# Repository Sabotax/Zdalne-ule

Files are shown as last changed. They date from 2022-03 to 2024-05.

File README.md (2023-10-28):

# Zdalne-ule
Projekt przejściowy oraz praca inżynierska oraz projekt kontynuowany prywatnie.
Polega na zbieraniu danych z uli pszczeli w celu ich zdalnego wykorzystania w optymalizacji pracy pszczelarza.  
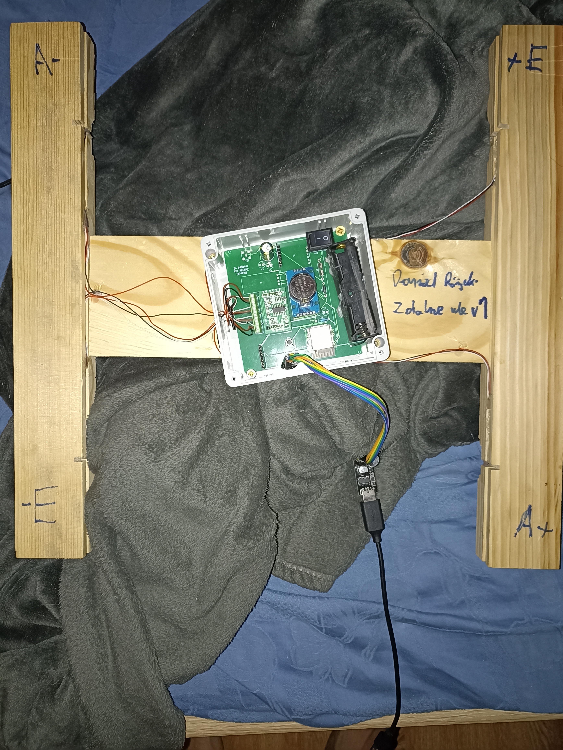
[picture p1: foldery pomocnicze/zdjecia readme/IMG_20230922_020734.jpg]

Używane technologie: 
	- C++ od strony mikontrolerów,
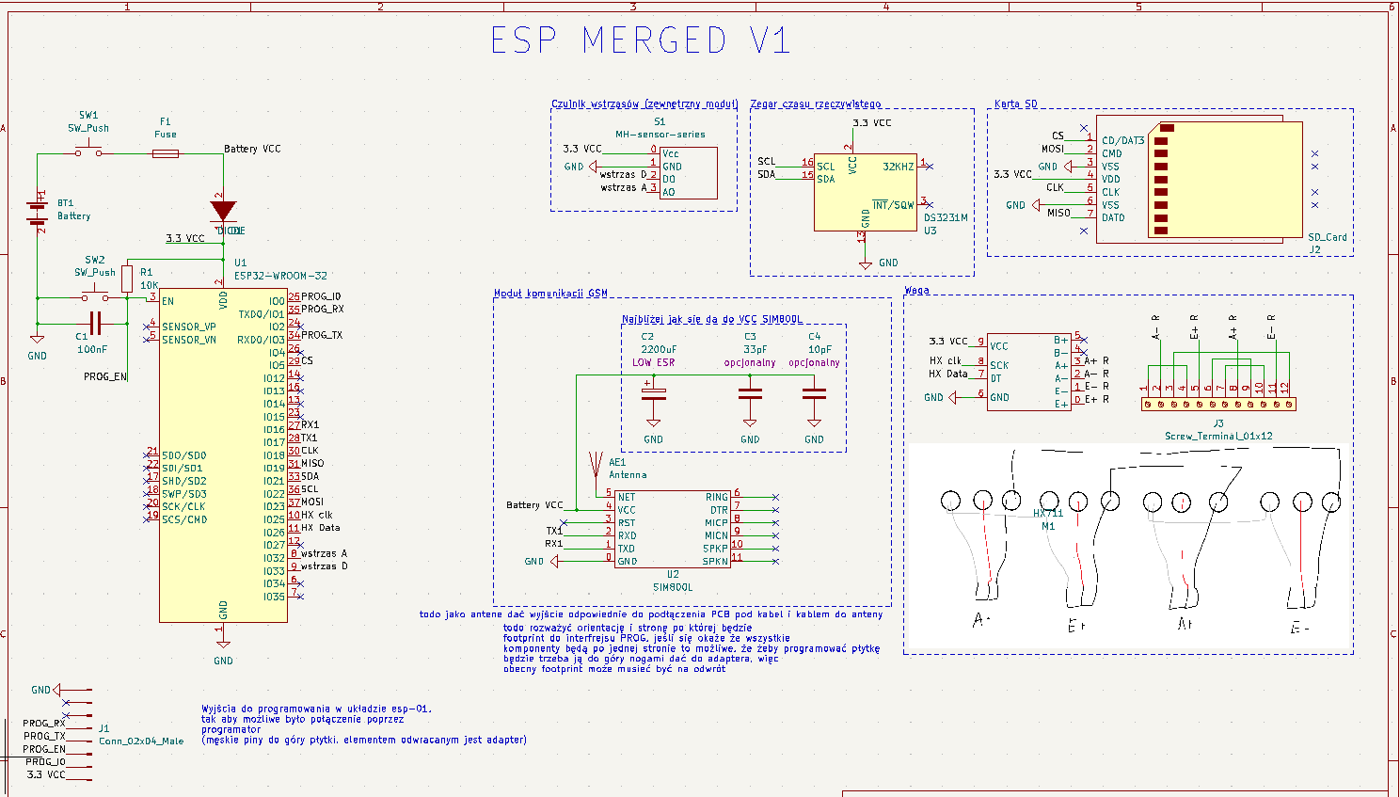
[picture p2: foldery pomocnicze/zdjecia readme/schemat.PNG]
	
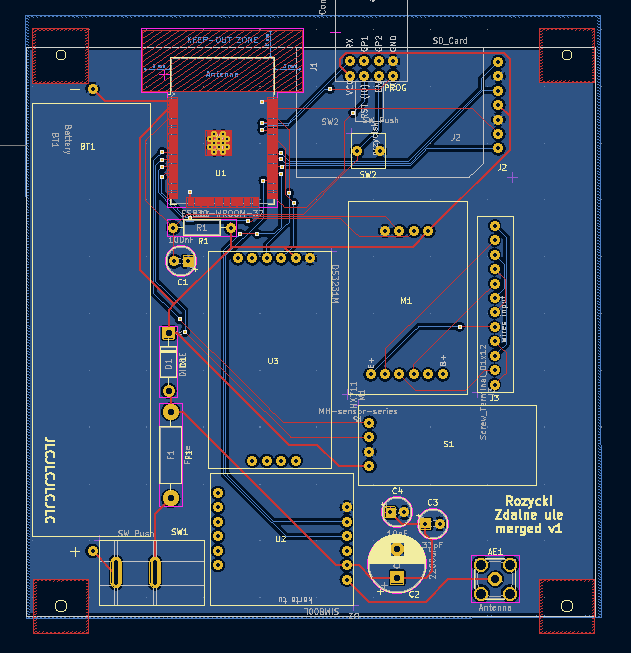
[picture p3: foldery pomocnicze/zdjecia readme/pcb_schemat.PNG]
	
 \
	- Javascript/PHP od strony serwera
 \
	- Kotlin od strony aplikacji mobilnej
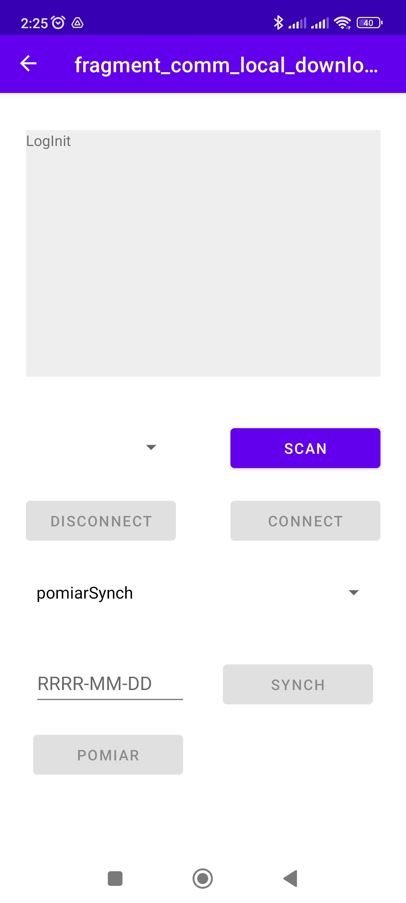
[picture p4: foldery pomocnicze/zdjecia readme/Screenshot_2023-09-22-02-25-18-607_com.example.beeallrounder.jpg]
	
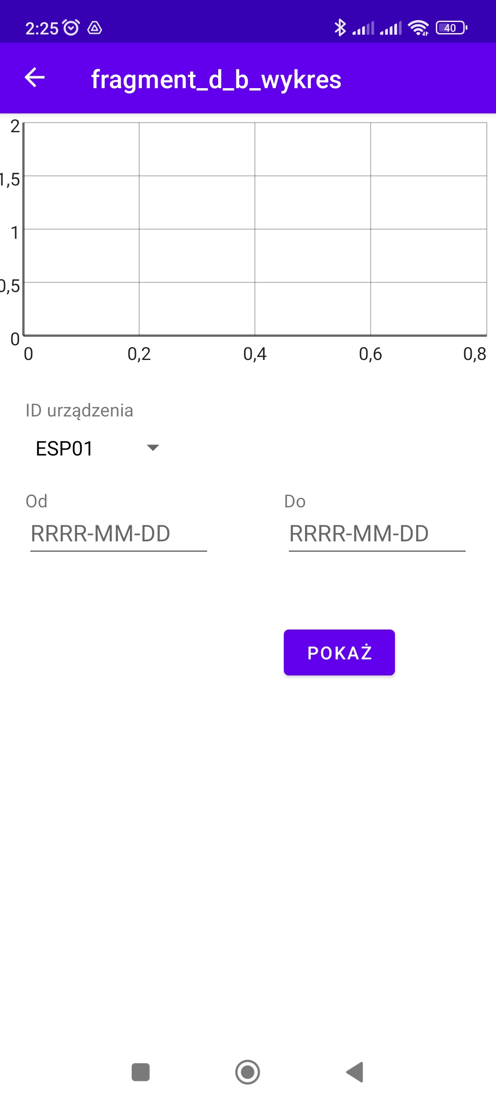
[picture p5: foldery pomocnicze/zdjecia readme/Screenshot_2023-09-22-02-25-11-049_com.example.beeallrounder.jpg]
	
Prezentacja  
https://prezi.com/view/HmCi9ISC9FMyPvuT7w0S/

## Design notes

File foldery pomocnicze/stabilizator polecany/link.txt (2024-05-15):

https://forum.arduino.cc/t/ldo-voltage-regulators-for-battery-powering-esp32/1142854/14

RT9193 

RT-9020

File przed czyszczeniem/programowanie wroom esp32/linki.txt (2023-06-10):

https://www.elektroda.pl/rtvforum/topic3903815.html
https://forbot.pl/forum/topic/18629-jak-wyglada-uklad-cp2102-w-esp32-devkit/

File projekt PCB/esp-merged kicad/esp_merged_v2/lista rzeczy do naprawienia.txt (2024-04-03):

1. prawidłowo ułożyć piny do programowania -> porzucone, rj45 DONE
2. przycisk do programowania -> porzucone, rj45 DONE
3. podpisać też przyciski i piny prog, opcjonalnie -> porzucone, rj45 DONE
4. piny/wyjścia pod przycisk do wybudzania -> DONE
5. piny pod led wybudzający -> DONE
6. czujnik wstrząsu zostawić -> DONE [ ono będzie musiało być na ext1 w budzeniu chyba ]
7. poprawić rozstaw dla schematu sim800L (chyba o milimetr się nie zgadzał)
8. jak się uda, to niech interfejs PROG nie zasłania karty SD -> porzucone, rj45

----
9. do programowania zrobić tylko gniazdo ethernet na PCB i osobny mały układ do programowania na prototypowej zamiast PROG
10. sim800L ma miec przylaczony pin do usypiania go [ usypianie prawie na pewno przez komende, a budzenie przez pin dtr ], potwierdzic, ale jak tak to DONE
11. !!!! być może inne rozwiązanie bateriowe nie jest potrzebne, jeśli użyjemy panelu słonecznego i ładowania Li-Pol TP4056 ! (chyba mam jeden w pudle)

led ma mieć 100ohm max rezystor, wg obliczeń 36

zrobić 2 ogniwa baterii z TP0456 zamiast jednego

----
rozdzielić baterie na osobne pudełko, w nim dać interfejs do podłączenia solarów na zewnątrz, oraz interfejs na kable do samego zdalnego ula
oraz wskaznik baterii np 
https://allegro.pl/oferta/wskaznik-poziomu-naladowania-baterii-ogniwa-1s-8s-13887584781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
oraz wyjście usb oczywiście z tp4056 do ładowania

w nowym designie: usb z żyłami rt tx do esp32 prosto, dodatkowo:
miejsce na kondensator na zasilanie tylko dla esp32 (też się lubi resetować, na to wygląda, nie musi być tak duży jak dla sim)

TODO
sprawdzić TP4056 czy jak damy mu 5V na wejście ładowania to na wyjściu będzie dawał 4.2 V jak z baterii

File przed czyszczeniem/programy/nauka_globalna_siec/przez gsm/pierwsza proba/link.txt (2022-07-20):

https://randomnerdtutorials.com/esp32-cloud-mqtt-broker-sim800l/
https://www.youtube.com/watch?v=HjFX40tYIec

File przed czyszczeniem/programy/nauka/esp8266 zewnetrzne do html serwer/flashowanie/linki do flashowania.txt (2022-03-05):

https://www.allaboutcircuits.com/projects/flashing-the-ESP-01-firmware-to-SDK-v2.0.0-is-easier-now/
https://www.allaboutcircuits.com/projects/update-the-firmware-in-your-esp8266-wi-fi-module/

+setup z poprzedniego poprzez arduino
+ nie wiem czy konieczne, ale zasilanie jest zewnętrzne (do 10A), a TX z arduino zbite do 3.3

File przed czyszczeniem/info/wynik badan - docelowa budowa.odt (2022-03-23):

Główmy mikrokontroler – nodemcu esp8266 lub jakiś esp8266 z wystarczająca ilością portów 15 zł

Zegar RTC DS33 coś tam, żeby miał możliwość użycia alarmów 10zł

Low power który będzie przerywany poprzez czujnik wstrząsów lub alarm z RTC (musi też być znany powód wybudzenia). 5zł

Czujnik temperatury sonda dallas, waga wraz z hx711 20-25zł

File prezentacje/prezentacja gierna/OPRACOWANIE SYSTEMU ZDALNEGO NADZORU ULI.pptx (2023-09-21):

## OPRACOWANIE SYSTEMU ZDALNEGO NADZORU ULI PSZCZELICH

Autor: Daniel Różycki
Promotor: dr inż. Michał Fularz

## Problem

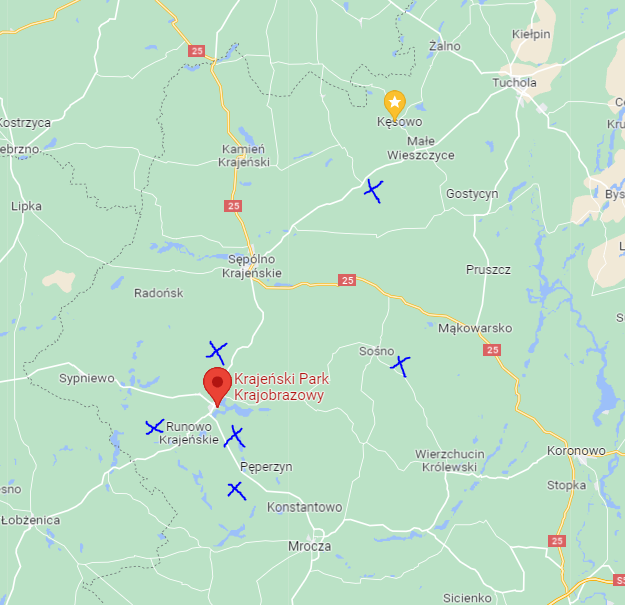
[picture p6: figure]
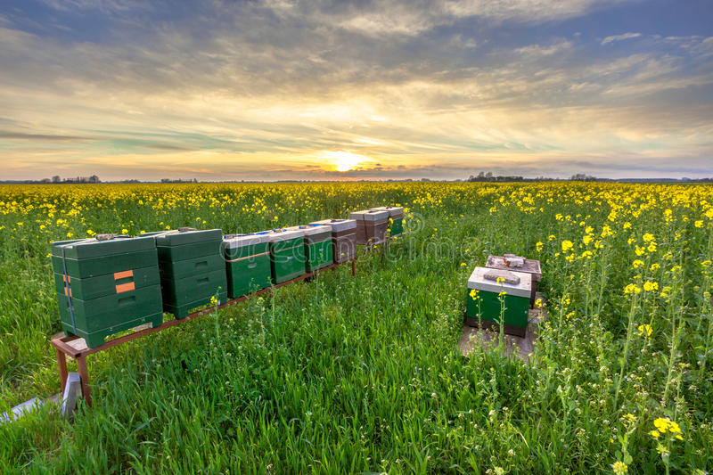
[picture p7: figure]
Rząd ule w polu obraz stock. Obraz złożonej z wiejski - 50957907

## Konkurencja, koszty

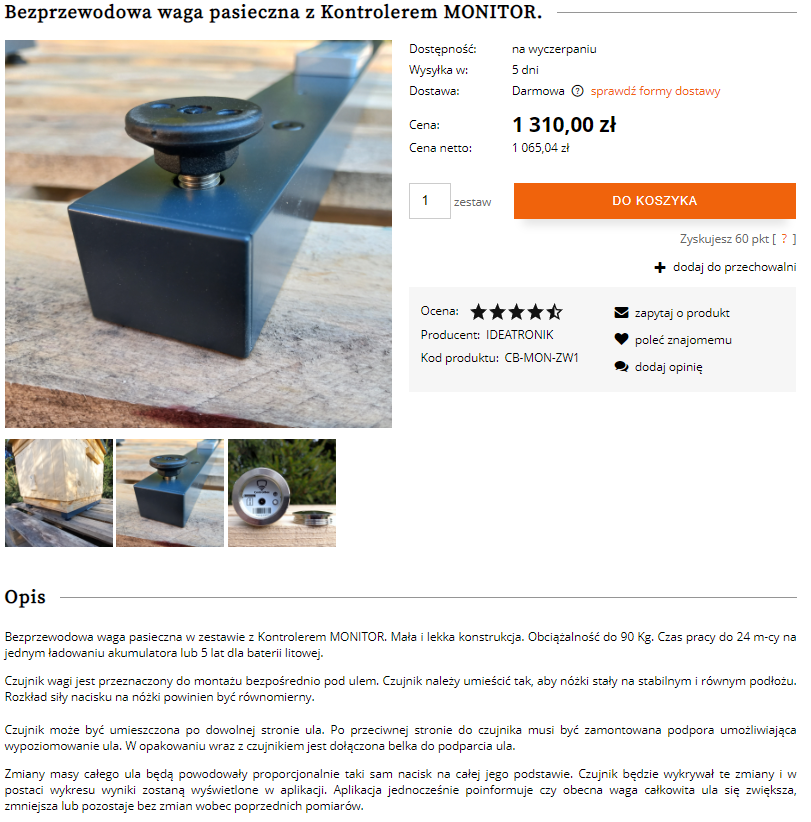
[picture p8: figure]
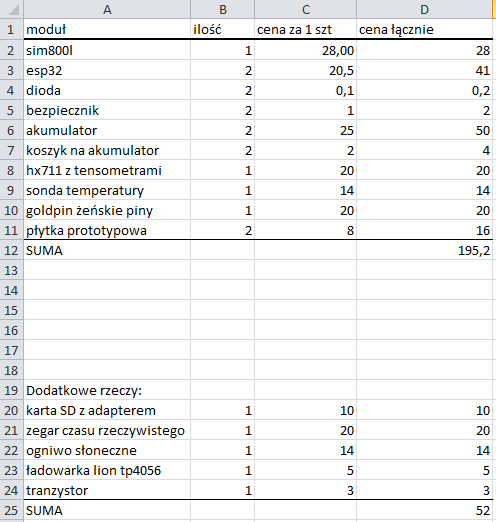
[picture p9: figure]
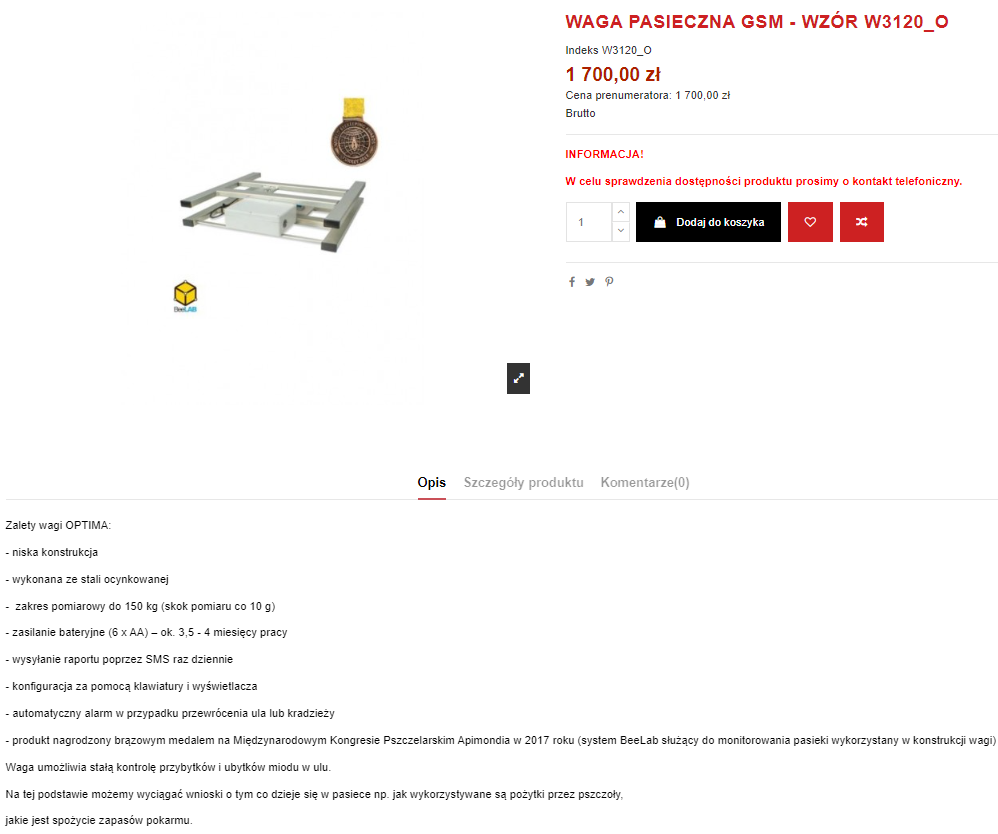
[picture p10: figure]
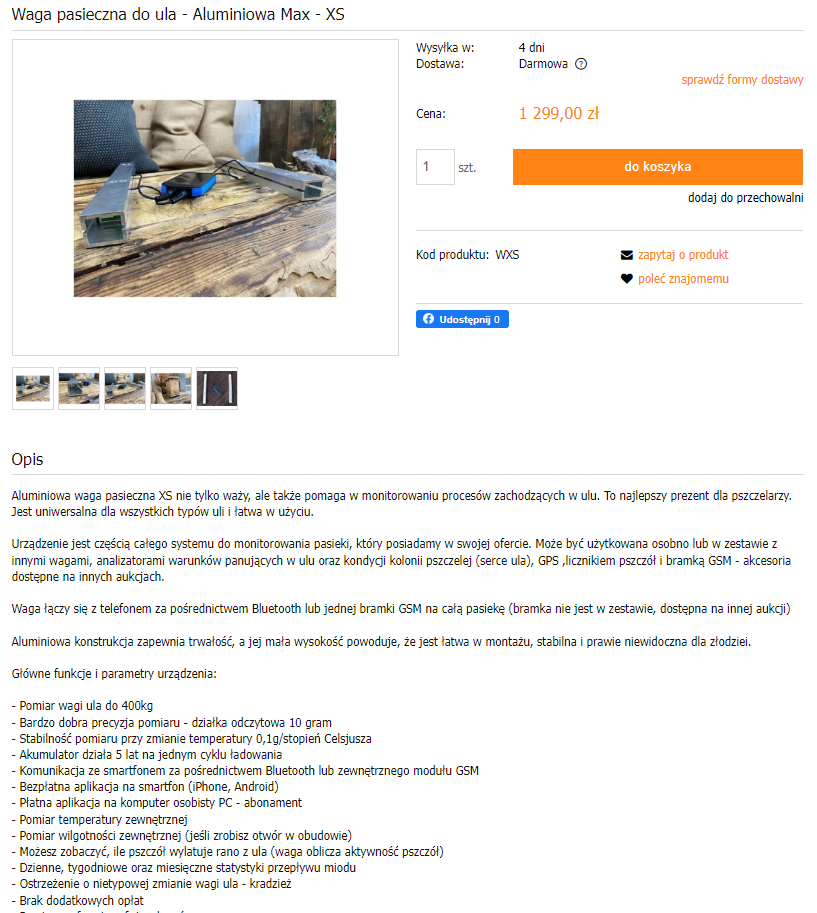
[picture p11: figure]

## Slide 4

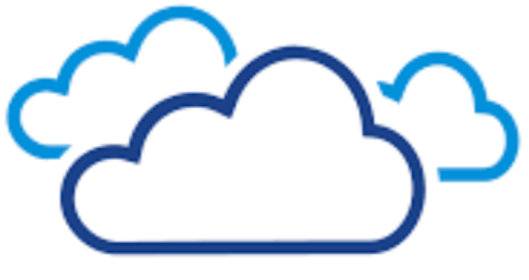
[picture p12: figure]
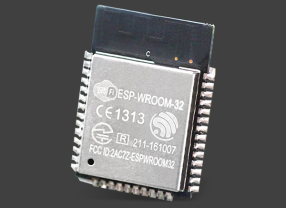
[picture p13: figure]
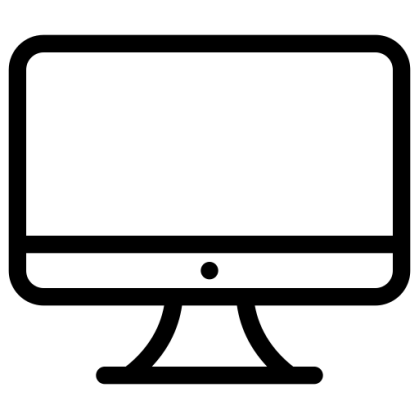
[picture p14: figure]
Computer icon (png symbol) black
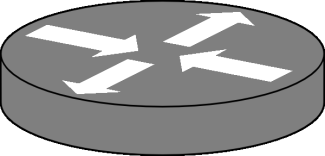
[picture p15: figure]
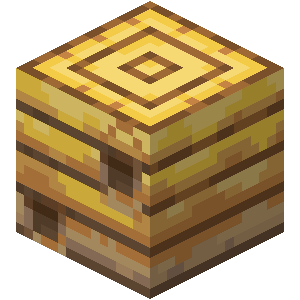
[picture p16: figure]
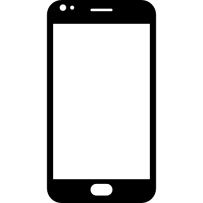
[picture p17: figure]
Free Icon | Smartphone

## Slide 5

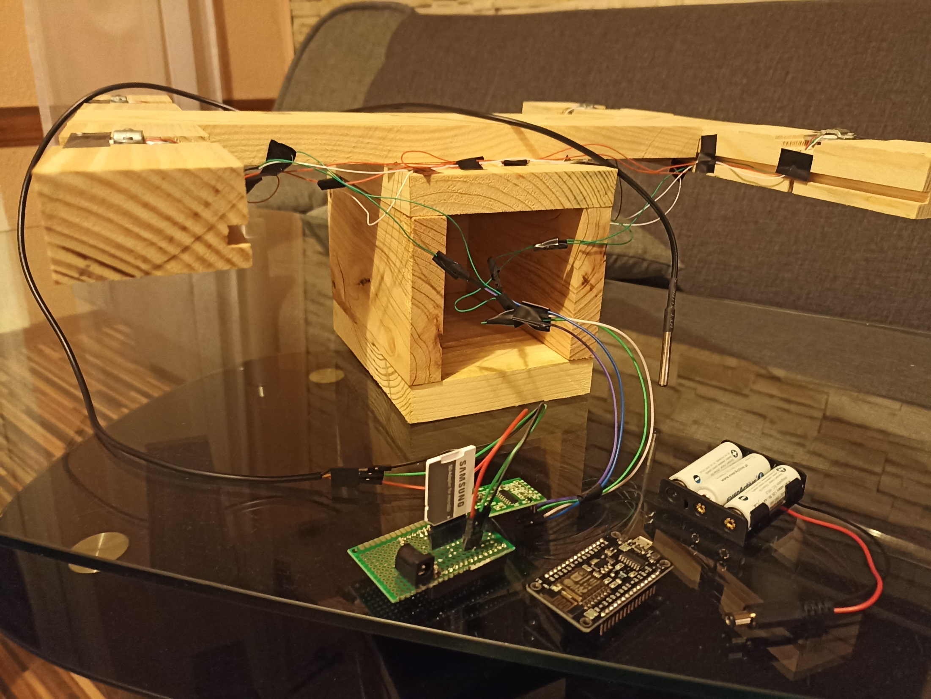
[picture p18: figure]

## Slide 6

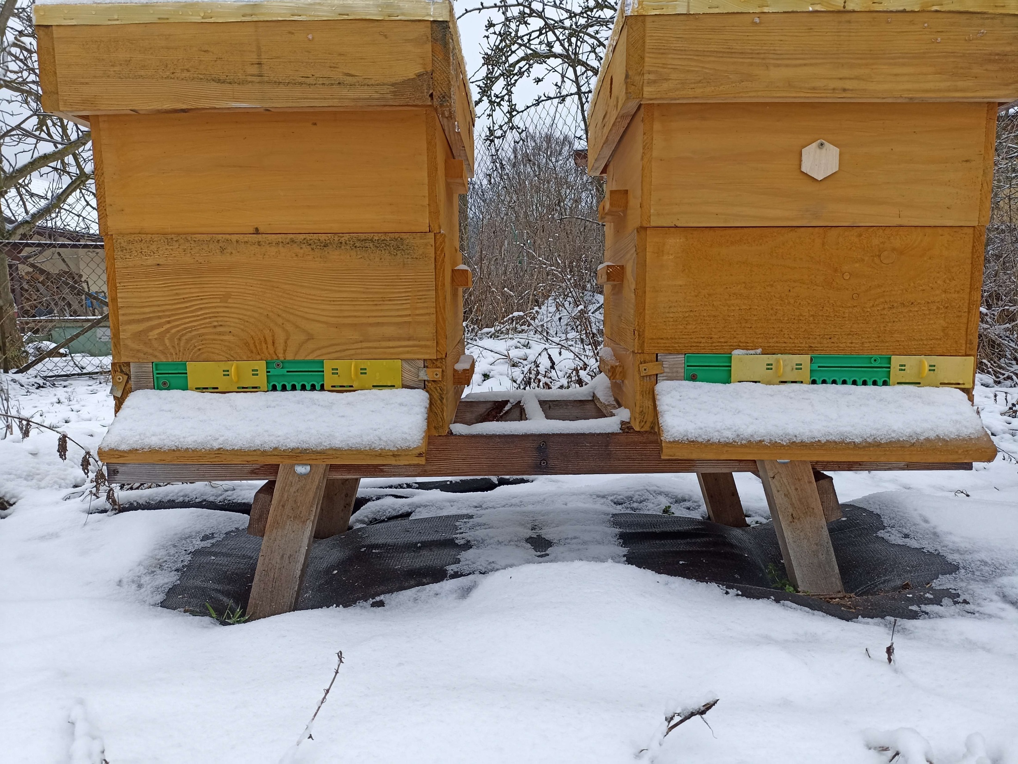
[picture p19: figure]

- TODO zdjęcie ławeczki od Damiana

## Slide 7

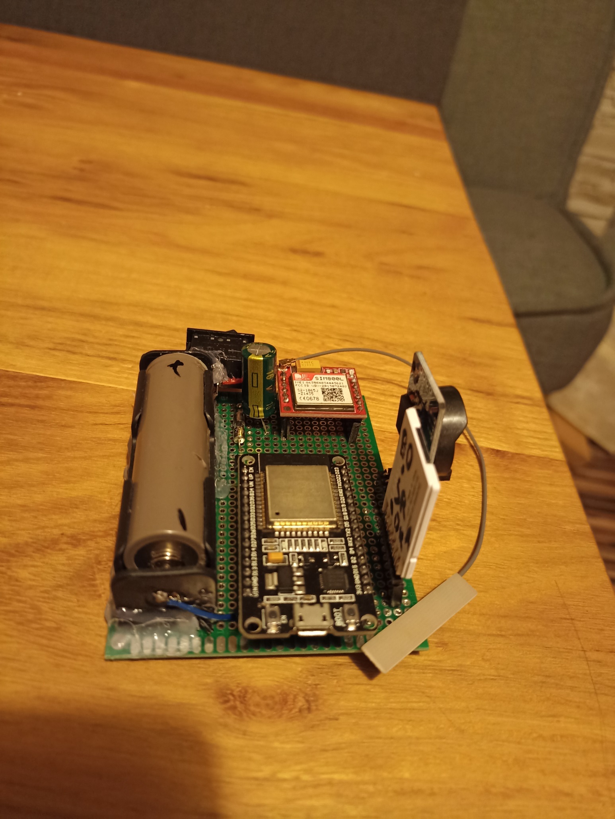
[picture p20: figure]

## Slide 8

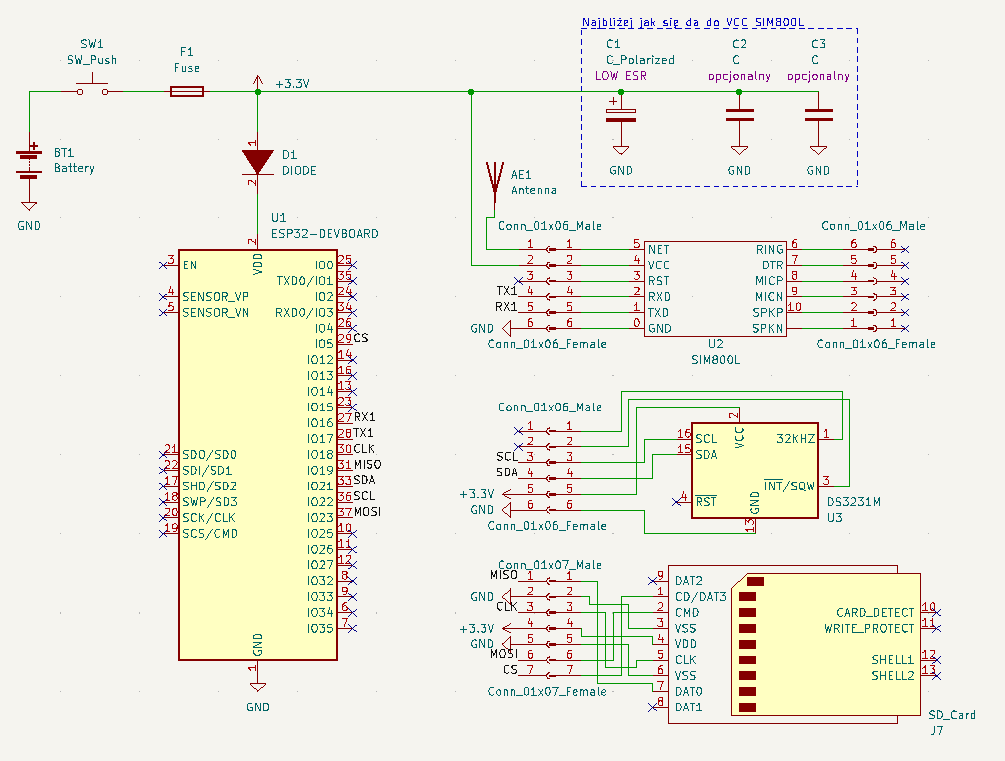
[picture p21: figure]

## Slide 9

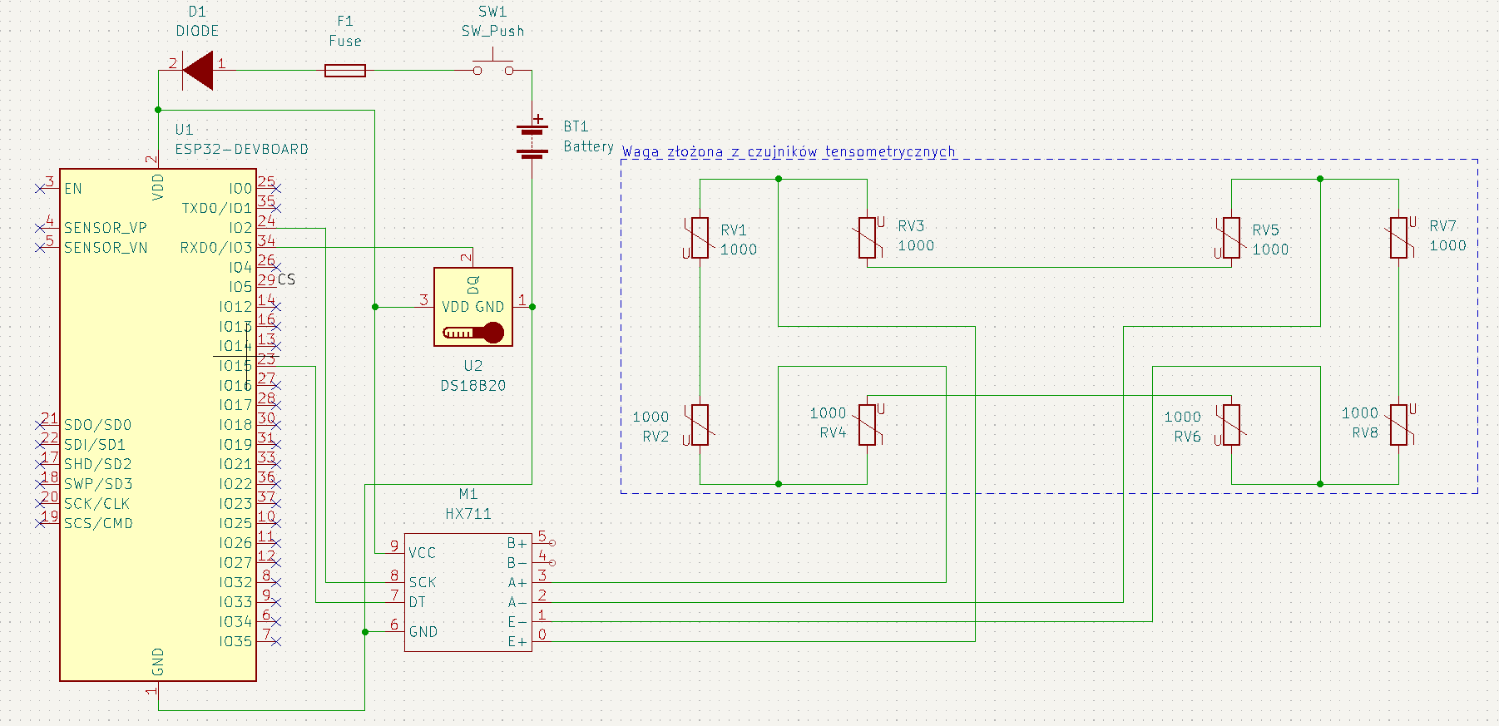
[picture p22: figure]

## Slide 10

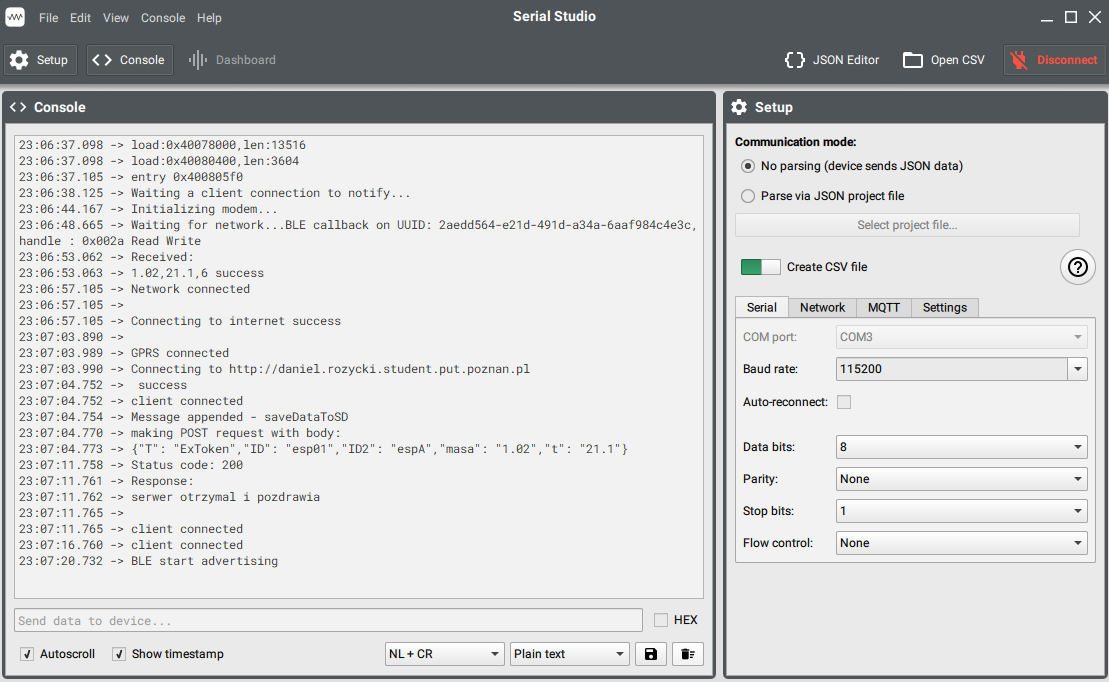
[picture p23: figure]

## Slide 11

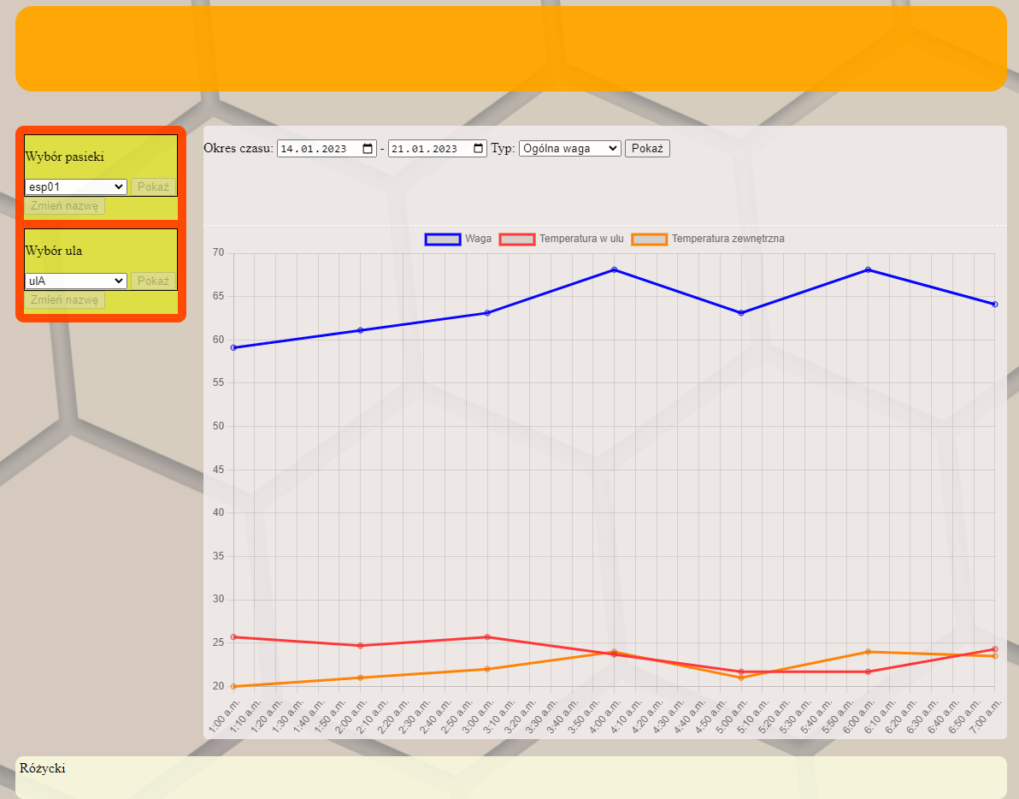
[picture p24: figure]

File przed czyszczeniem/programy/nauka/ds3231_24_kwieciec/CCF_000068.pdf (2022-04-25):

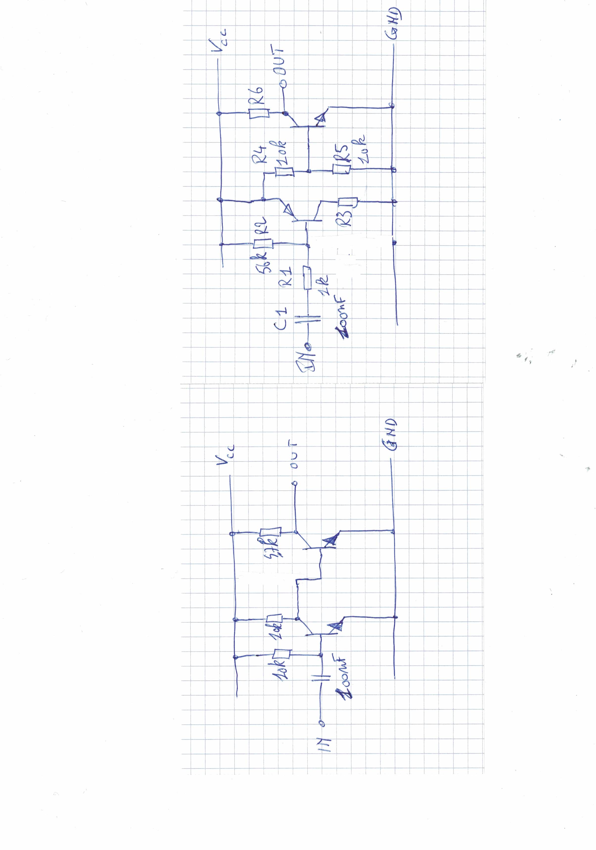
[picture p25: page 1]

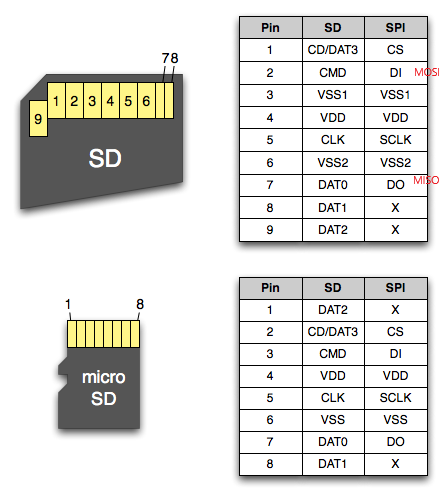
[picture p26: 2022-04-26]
przed czyszczeniem/programy/poprzednie_wersje/offline_zbieranie_danych_v3/sd-card-pinout.png

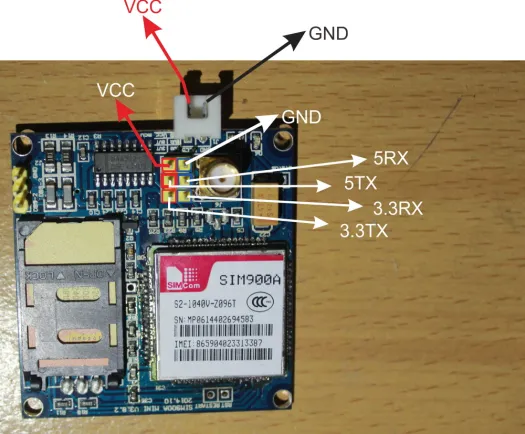
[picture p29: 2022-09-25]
przed czyszczeniem/programy/nauka_globalna_siec/przez gsm/sim900A/Pinout-smaller.webp

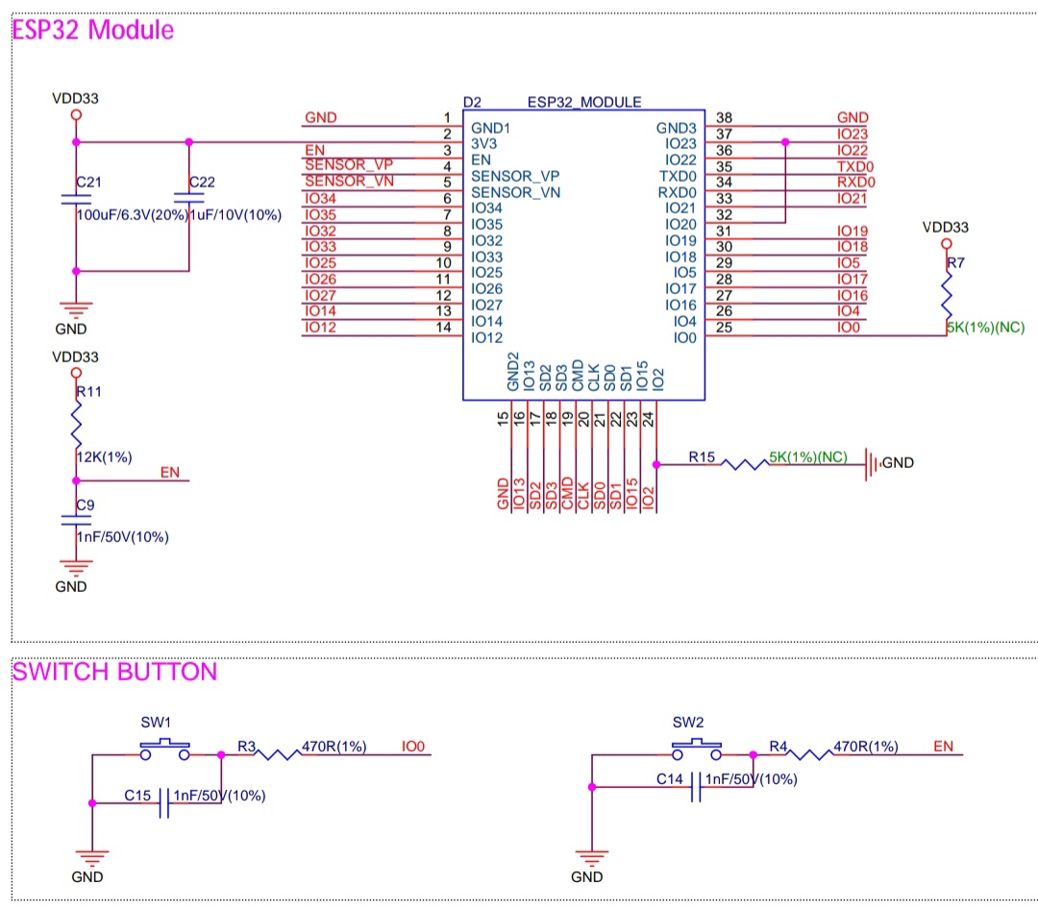
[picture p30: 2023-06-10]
przed czyszczeniem/programowanie wroom esp32/esp programming schematic.jpeg

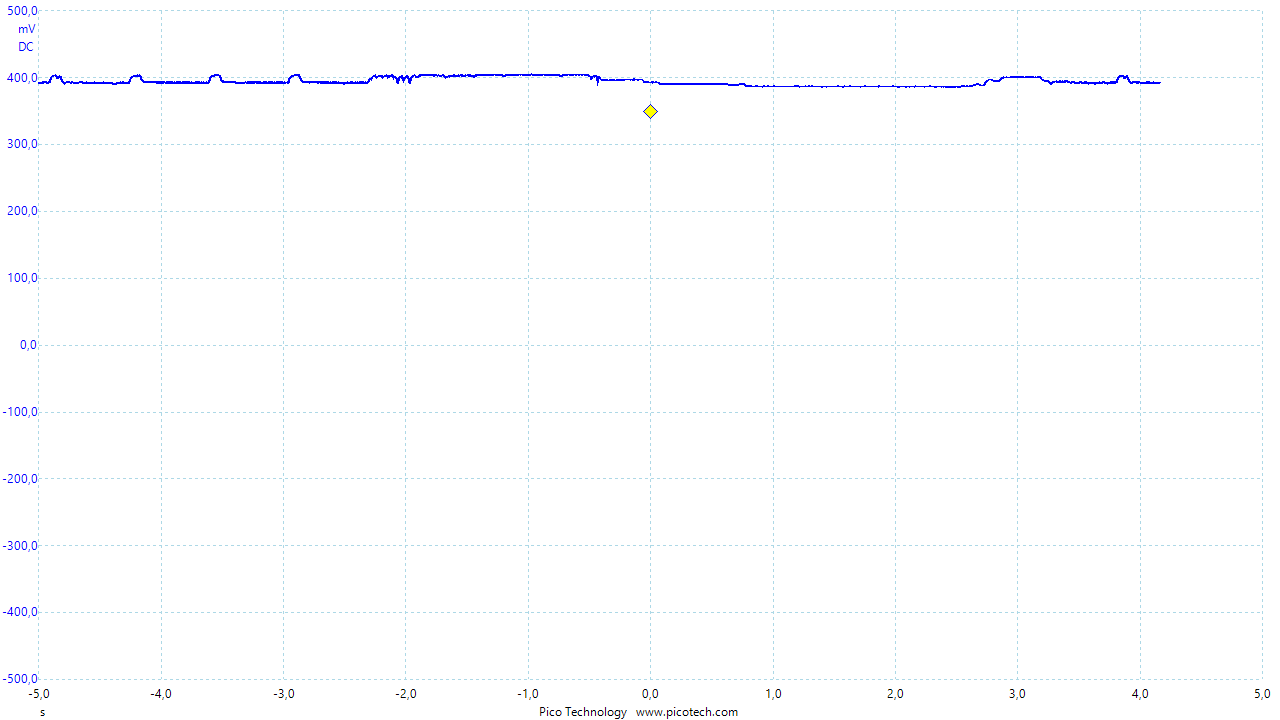
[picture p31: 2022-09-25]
przed czyszczeniem/programy/nauka_globalna_siec/oscyloskop/lion_zasilanie.png

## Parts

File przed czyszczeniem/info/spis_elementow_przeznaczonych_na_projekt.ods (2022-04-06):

Element | Cena | Ilość | Stan zrobienia | Link do strony zakupu | Link do strony poradnika 1 | Link do strony poradnika 2 |  |  | Adnotacja
Sonda temperatury DS18B20+ | 9.90 | 1.00 |  | allegro (https://allegro.pl/oferta/czujnik-temperatury-ds18b20-1m-wodoodpor-termometr-7349008662) | botland (https://botland.com.pl/content/134-arduino-w-polaczeniu-z-czujnikiem-temperatury-ds18b20)
Moduł czasu rzeczywistego DS1307 | 3.99 | 1.00 |  | allegro (https://allegro.pl/oferta/modul-czasu-rtc-ds1307-24c32-zegara-bateria-avr-7180823856) | botland (https://botland.com.pl/moduly-rtc/12507-rtc-ds1307-32kb-eeprom-24c32-i2c-zegar-czasu-rzeczywistego-z-pamiecia-5904422341121.html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)
ESP-01 ESP8266 | 8.80 | 1.00 | zrobione wystarczająco | allegro (https://allegro.pl/oferta/modul-wifi-esp-01-esp8266-arduino-fv-esp8266ex-7283905143)
ESP8266 NodeMcu V3 | 16.40 | 1.00 | zrobione wystarczająco | allegro (https://allegro.pl/oferta/modul-wifi-esp8266-nodemcu-v3-ch340-lua-arduino-fv-7349004970) |  |  |  |  | możliwe ze mniejszy kaliber starczy (albo większy w stosunku do esp-01 8266
nRF24L01A1100 | 15.80 | 1.00 |  | allegro (https://allegro.pl/oferta/modul-bezprzewodowy-nrf24l01-antena-2-4ghz-arduino-7973830280)
czujnik ruchu SW-18010P MH-series | 4.80 | 1.00 |  | allegro (https://allegro.pl/oferta/modul-czujnik-wibracji-ruchu-drgan-sw-18010p-ardui-11498116170) | producent (https://einstronic.com/product/sw18010p-vibration-switch-sensor-module/) | yt (https://www.youtube.com/watch?v=hDqkDn6dVJ4) |  |  | możliwe jest użycie tylko sw-18 itp. ponieważ ono daje analog output, a ten użyty cały moduł daje i analog i output, więc możliwe że lepiej będzie go użyć przy wake-up przy zasypianiu arduino
moduł pamięci flash | 6.50 | 1.00 |  | allegro (https://allegro.pl/oferta/modul-pamieci-flash-spi-w25q32b-arduino-32mbit-10163337080)
czujnik tensometryczny | 1.41 | 4.00 |  | ali (https://www.aliexpress.com/item/1005002176327047.html?spm=a2g0o.order_list.0.0.21ef1802esItvU)
wzmacniacz HX711 | 2.73 | 1.00 |  | ali (https://www.aliexpress.com/item/1005002176327047.html?spm=a2g0o.order_list.0.0.21ef1802esItvU)
gps GY-NEO6MV2 | 14.85 | 1.00 |  | ali (https://www.aliexpress.com/item/1005001635722164.html?spm=a2g0o.order_list.0.0.21ef1802esItvU)
gsm SIM800L | 16.69 | 1.00 |  | ali (https://www.aliexpress.com/item/4001340742257.html?spm=a2g0o.order_list.0.0.21ef1802esItvU)
czytnik karty sd | 9.79 | 1.00 |  | allegro (https://allegro.pl/oferta/czytnik-kart-micro-sd-dla-arduino-stm32-9336705585) | https://diyi0t.com/sd-card-arduino-esp8266-esp32/ | https://alexlubbock.com/micro-sd-adapter-esp8266-esp32 | https://randomnerdtutorials.com/esp32-microsd-card-arduino/ | https://www.mischianti.org/2019/12/15/how-to-use-sd-card-with-esp8266-and-arduino/

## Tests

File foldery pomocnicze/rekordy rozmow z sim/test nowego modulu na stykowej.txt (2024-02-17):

22:28:24.536 -> AT
22:28:24.536 -> OK
22:28:48.564 -> AT+SAPBR=3,1,"Contype","GPRS"
22:28:48.564 -> OK
22:29:02.032 -> AT+SAPBR=3,1,"APN","internet"
22:29:02.032 -> OK
22:29:22.011 -> AT+SAPBR=3,1,"USER",""
22:29:22.011 -> OK
22:29:31.465 -> AT+SAPBR=3,1,"PWD",""
22:29:31.465 -> OK
22:29:38.359 -> AT+SAPBR=1,1
22:29:38.823 -> OK
22:29:43.046 -> AT+SAPBR=2,1
22:29:43.046 -> +SAPBR: 1,1,"100.103.171.15"
22:29:43.062 -> 
22:29:43.062 -> OK
22:29:52.179 -> AT+CNUM
22:29:52.195 -> OK
22:30:05.040 -> AT+CNUM
22:30:05.055 -> OK
22:30:25.834 -> AT+CNUM=?
22:30:25.834 -> OK
22:30:46.693 -> AT+CSQ
22:30:46.693 -> +CSQ: 23,0
22:30:46.693 -> 
22:30:46.693 -> OK
22:30:50.868 -> AT+CBC
22:30:50.868 -> +CBC: 0,100,4965
22:30:50.868 -> 
22:30:50.868 -> OK
22:31:00.257 -> AT+CREG?
22:31:00.257 -> +CREG: 0,5
22:31:00.257 -> 
22:31:00.257 -> OK
22:31:57.466 -> AT+CNUM
22:31:57.482 -> OK
22:32:45.750 -> AT
22:32:45.750 -> OK
22:32:47.268 -> AT+HTTPINIT
22:32:47.268 -> OK
22:33:01.758 -> AT+HTTPPARA="CID",1
22:33:01.758 -> OK
22:34:00.946 -> AT+HTTPPARA="URL","http://damian.rozycki.student.put.poznan.pl/incomingData.php"
22:34:00.967 -> OK
22:34:14.947 -> AT+HTTPPARA="CONTENT","application/json"
22:34:14.963 -> OK
22:35:17.098 -> AT+HTTPDATA=13,100000
22:35:17.098 -> DOWNLOAD
22:35:23.992 -> 
22:35:23.992 -> OK
22:35:44.799 -> AT+HTTPACTION=1
22:35:44.799 -> OK
22:35:46.494 -> 
22:35:46.494 -> +HTTPACTION: 1,403,0
22:38:12.529 -> AT+HTTPDATA=76,100000
22:38:12.529 -> DOWNLOAD
22:38:20.413 -> 
22:38:20.413 -> OK
22:38:24.443 -> AT+HTTPACTION=1
22:38:24.443 -> OK
22:38:25.466 -> 
22:38:25.466 -> +HTTPACTION: 1,200,32

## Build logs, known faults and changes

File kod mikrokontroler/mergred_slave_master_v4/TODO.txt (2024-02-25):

dodać synchro czasu z telefonu na układ

sprawdzic czy synchroSd zadziała dla txt

sprobowac przetestować SD nie na zdalnym ulu a na własnym obwodzie

https://interrupt.memfault.com/blog/ble-throughput-primer

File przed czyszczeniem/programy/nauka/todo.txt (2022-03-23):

połączyć deep sleep oraz wifi client na node

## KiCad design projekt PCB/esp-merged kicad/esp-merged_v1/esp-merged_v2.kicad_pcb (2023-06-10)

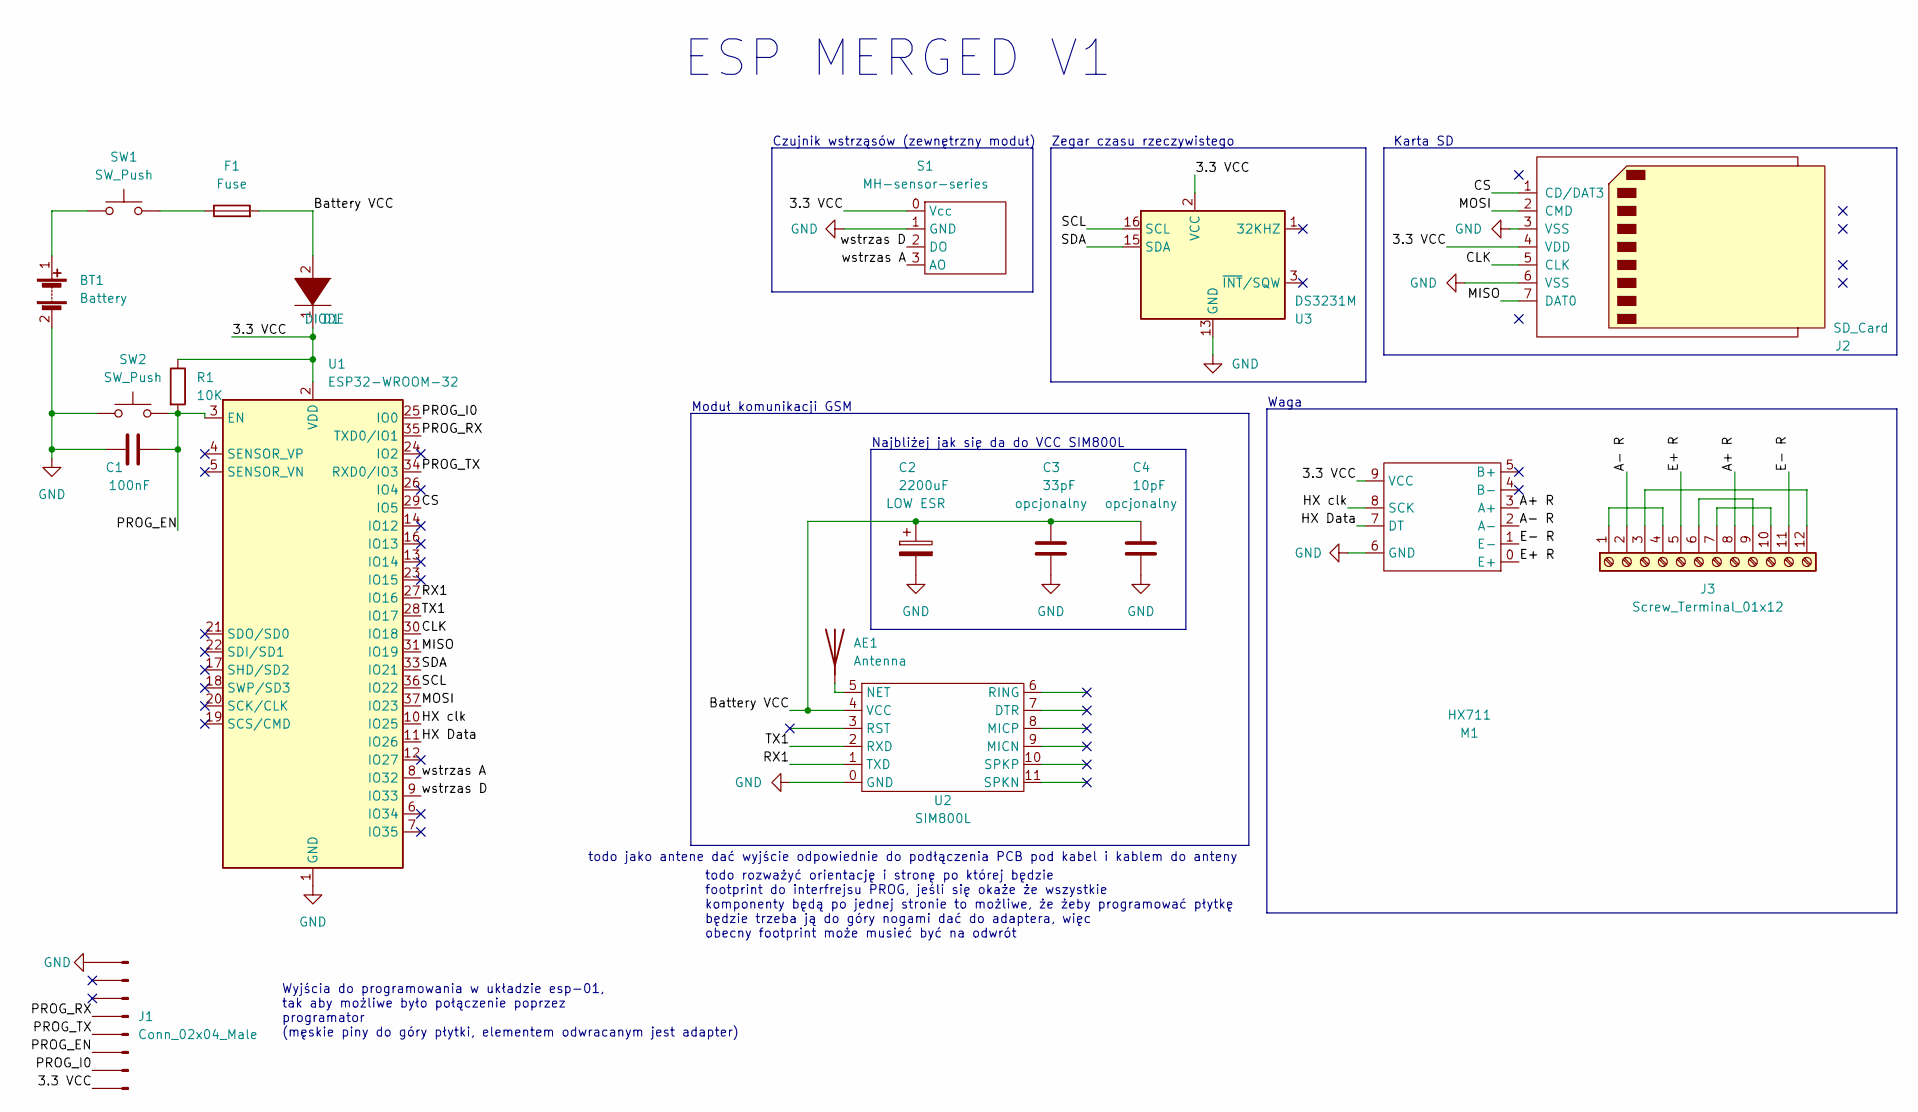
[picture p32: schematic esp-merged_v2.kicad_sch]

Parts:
AE1: Antenna; SMA_Amphenol_132291_Vertical
BT1: Battery; koszyk na baterie 1x1
C1: 100nF; CP_Radial_Tantal_D5.0mm_P2.50mm
C2: 2200uF; CP_Radial_D10.0mm_P5.00mm
C3: 33pF; CP_Radial_Tantal_D5.0mm_P2.50mm
C4: 10pF; CP_Radial_Tantal_D5.0mm_P2.50mm
D1: DIODE; D_A-405_P10.16mm_Horizontal
F1: Fuse; R_Axial_DIN0411_L9.9mm_D3.6mm_P15.24mm_Horizontal
J1: Conn_02x04_Male; prog pins ESP32 (aka esp01) v2 (odwrocone)
J2: SD_Card; karta sd
J3: Screw_Terminal_01x12; screw connector 12
M1: HX711; hx711
R1: 10K; R_Axial_DIN0207_L6.3mm_D2.5mm_P10.16mm_Horizontal
S1: MH-sensor-series
SW1: SW_Push; wlacznik
SW2: SW_Push; mały button
U1: ESP32-WROOM-32
U2: SIM800L; sim800l
U3: DS3231M; ds3231

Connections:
/3.3 VCC: D1.1 (A), J1.1, J2.4 (VDD), M1.9 (VCC), R1.1, S1.0 (Vcc), U1.2 (VDD), U3.2 (VCC)
/A+ R: J3.8, M1.3 (A+)
/A- R: J3.2, M1.2 (A-)
/Battery VCC: C2.1, C3.1, C4.1, D1.2 (K), F1.2, U2.4 (VCC)
/CLK: J2.5 (CLK), U1.30 (IO18)
/CS: J2.1 (CD/DAT3), U1.29 (IO5)
/E+ R: J3.5, M1.0 (E+)
/E- R: J3.11, M1.1 (E-)
/HX Data: M1.7 (DT), U1.11 (IO26)
/HX clk: M1.8 (SCK), U1.10 (IO25)
/MISO: J2.7 (DAT0), U1.31 (IO19)
/MOSI: J2.2 (CMD), U1.37 (IO23)
/PROG_EN: C1.2, J1.3, R1.2, SW2.2, U1.3 (EN)
/PROG_I0: J1.2, U1.25 (IO0)
/PROG_RX: J1.5, U1.35 (TXD0/IO1)
/PROG_TX: J1.4, U1.34 (RXD0/IO3)
/RX1: U1.27 (IO16), U2.1 (TXD)
/SCL: U1.36 (IO22), U3.16 (SCL)
/SDA: U1.33 (IO21), U3.15 (SDA)
/TX1: U1.28 (IO17), U2.2 (RXD)
/wstrzas A: S1.3 (AO), U1.8 (IO32)
/wstrzas D: S1.2 (DO), U1.9 (IO33)
GND: BT1.2 (-), C1.1, C2.2, C3.2, C4.2, J1.8, J2.3 (VSS), J2.6 (VSS), M1.6 (GND), S1.1 (GND), SW2.1, U1.1 (GND), U1.15 (GND), U1.38 (GND), U1.39 (GND), U2.0 (GND), U3.13 (GND)
unnamed: AE1.1 (A), U2.5 (NET)
unnamed: BT1.1 (+), SW1.1
unnamed: F1.1, SW1.2
unnamed: J3.1, J3.4
unnamed: J3.6, J3.9
unnamed: J3.7, J3.10
unnamed: J3.3, J3.12

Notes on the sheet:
ESP MERGED V1
Karta SD
todo rozważyć orientację i stronę po której będzie footprint do interfrejsu PROG, jeśli się okaże że wszystkie komponenty będą po jednej stronie to możliwe, że żeby programować płytkę będzie trzeba ją do góry nogami dać do adaptera, więc obecny footprint może musieć być na odwrót
Najbliżej jak się da do VCC SIM800L
Czujnik wstrząsów (zewnętrzny moduł)
Zegar czasu rzeczywistego
todo jako antene dać wyjście odpowiednie do podłączenia PCB pod kabel i kablem do anteny
Waga
Moduł komunikacji GSM
Wyjścia do programowania w układzie esp-01, tak aby możliwe było połączenie poprzez programator (męskie piny do góry płytki, elementem odwracanym jest adapter)

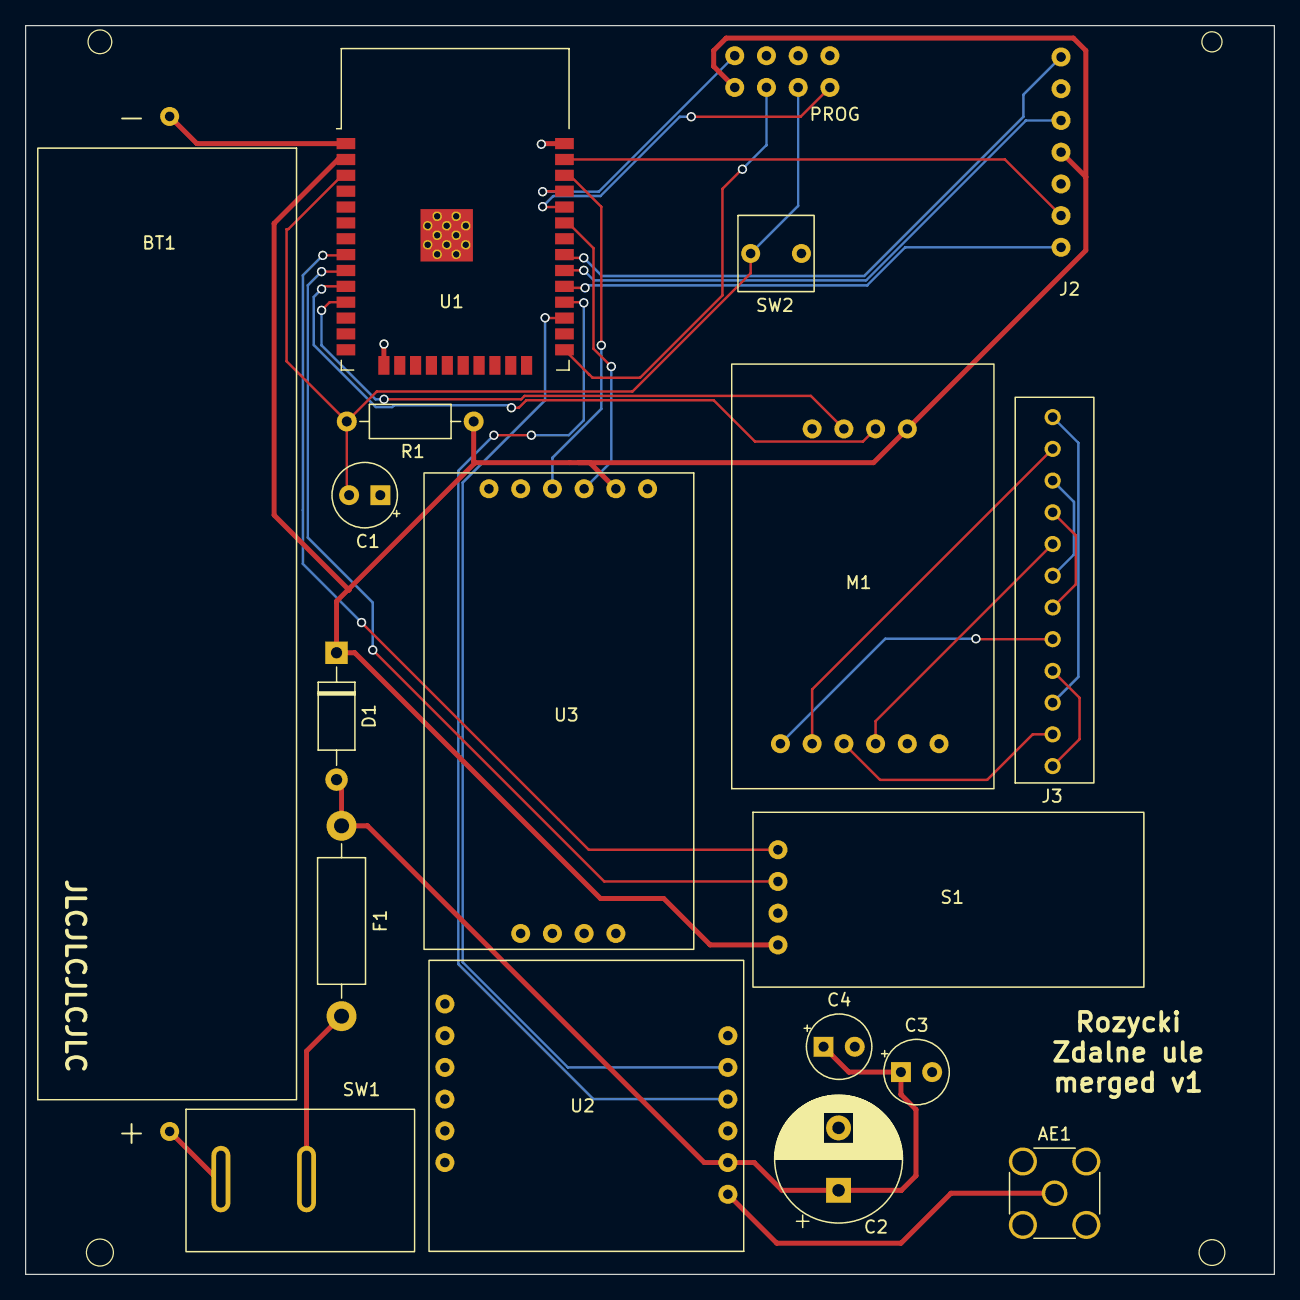
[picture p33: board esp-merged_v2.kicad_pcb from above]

Board: 2 copper layers, 100.0 x 100.0 mm, 19 parts (0 on the bottom side), 30 nets.

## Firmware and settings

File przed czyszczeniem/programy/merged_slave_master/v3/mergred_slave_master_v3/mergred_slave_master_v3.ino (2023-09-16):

/*
 * Zadania programu:
 * - inicjacja:
 *     - RTC: 
 *          - jeśli first uruchomienie z kompa to ustawia godzine
 *     - SD
 *     - HX711
 *     - WIFI lub GSM w zależności od opcji
 * - wake up cykl:
 *     - pobiera wage
 *     - zapisuje na SD wraz z timestampem
 *     - wysyła na serwer przez WiFi
 *     - idzie spać, cykl na nowo się zaczyna
 * - dodatkowa opcja BLE:
 *     - obudzenie/włączenie przełącznikiem fizycznym, które sprawia że esp chodzi tak długo jak jest przełączone (sygnalizowane ledem)
 *     - w tym czasie esp wystawia serwer/usługę, podczas której będzie można synchronizować dane z smartfonem przez bluetooth
 *     
 * Kolejne wersje mają mieć: budzenie dodatkowo przez czujnik wstrząsu, gps
 */
#define DEBUG
#define GSM_turn_on
#define BLE_turn_on
//#define mockData
//#define turnOnSD

#include "authData.h"

#include "MyHelper.h"
#include "MyRTC.h"
#include "MySD.h"
#include "MyWaga.h"

#ifdef BLE_turn_on
  #include "MyBLE.h"
#endif

#ifdef GSM_turn_on
  #include "MyGSM.h"
#else
  #include "MyWIFI.h"
#endif

void setup() {
  setCpuFrequencyMhz(80); //dla hx711
  Serial.begin(115200);

  delay(3000);

  digitalWrite(33,LOW);
  pinMode(33,OUTPUT);

  enableTouchWakeUp();

  didIwakeUpForBle();
  //print_wakeup_touchpad();
  //esp_sleep_pd_config(ESP_PD_DOMAIN_RTC_PERIPH, ESP_PD_OPTION_ON);

  #ifndef mockData
    initMyRTC();
    initMyWaga();
  #endif

  #ifdef turnOnSD
    initMySD();
  #endif

}

void loop() {

  if(false) {
    digitalWrite(33,HIGH);
    if( millis() > bleWakeUpMoment + (1000*60*5)) {
      // time's up, going to sleep
      Serial.println("time's up, going to sleep " + String(millis() ) + " " + String(bleWakeUpMoment));
      digitalWrite(33,LOW);
      handle_sleep();
    }
else {
      #ifdef BLE_turn_on
        initBLE();
      #endif
    
      if(input_received) {
        Serial.println("Przetwarzam input");
        input_received = false;

        //decode input

        String rozkaz = "";
        bool rozkaz_done = false;

        String data_incoming = "";
        
        for(uint8_t i = 0; i < input_size; i++) {
          //Serial.println("Char" + String(i) + "=( "+String(input_data[i])+" , "+String( (char) input_data[i] ) + " )");
          if(!rozkaz_done) {
            if(input_data[i] == '|') {
              rozkaz_done = true;
            }
            else {
              rozkaz += String( (char) input_data[i] );
            }
          }
          else {
            data_incoming += String( (char) input_data[i] );
          }
        }
        // input decoded
        Serial.println("rozkaz = " + rozkaz);
        Serial.println("dane = " + data_incoming);

        #ifdef turnOnSD

          if(rozkaz == "1") {
            // start sending data
            // TODO dekodowanie path?
            String path = "/"+data_incoming+".csv";
            Serial.println("Reading file: " + path);
  
            file = SD.open(path);
            if(!file){
              Serial.println("Failed to open file for reading");
              myTXstring(5,"0");
            }
            else {
              myTXstring(1,"");
            }
            
      
            // TODO jak zrobić otwieranie pliku i wysyłanie pomiędzy kolejnymi pętlami
            // deklaracja wyżej i otwieranie zamykanie w 1 i 3 ?
          }
  
          if(rozkaz == "2") {
            //continue sending data
            Serial.println("file "+ String((bool) file));
            if(file){
              String line = "";
              char c='#';
              
              while(file.available()){
                c = file.read();
                Serial.println(c);
              
                if(c == '#') {
                  // file ended
    
                  // TX with message(rozkaz) that file ended (and line)
                  file.close();
                  myTXrow(3,line);
                  break;
                }
                else if(c == ';') {
                  // line ended
    
                  // TX with line and rozkaz that is ready to continue
                  myTXrow(2,line);
                  break;
                }
                else {
                  line += String(c);
                }
              }
  
              if(!file.available()) {
                myTXstring(6,"");
                file.close();
              }
            }
            
          }

        #endif

        #ifndef mockData

          if(rozkaz == "4") {
            // send current weight
            wagaOdczyt = loadcell.get_units(2);
            Serial.println("wykonuje pomiar="+String(wagaOdczyt));
            myTXstring(4,String(wagaOdczyt));
          }
  
          if(rozkaz == "7") {
            // set offset to rtc and weight
            weight_offset = data_incoming.toFloat();
            loadcell.set_offset(weight_offset);
            myTXstring(7,"");
          }
  
          if(rozkaz == "8") {
            // set scale to rtc and weight
            weight_scale = data_incoming.toFloat();
            loadcell.set_scale(weight_scale);
            myTXstring(8,"");
          }
        #endif

        if(rozkaz == "10") {
          // TODO opcjonalnie set czas spania
        }

        #ifdef GSM_turn_on

          if(rozkaz == "11") {
            // Read current battery
            initMyGSM();
            delay(5000);
  
            String batteryPercent = String(getBattery());
            myTXstring(11,batteryPercent);
          }
  
          if(rozkaz == "12") {
            // Read current signal
            if(!isConnected()) {
              initMyGSM();
            }
            
            int signalStrength = getSignal();
            myTXstring(12,String(signalStrength));
          }
        #endif
      }
    }
  }
  else {
    #ifdef GSM_turn_on
      initMyGSM();
    #else
      initMyWIFI();
    #endif

    #ifdef mockData
      wagaOdczyt = random(100);
      String nowTimestampEpoch = String(random(10000));
      String batteryPercent = String(random(100));
    #else
      wagaOdczyt = loadcell.get_units(2);
      String nowTimestampEpoch = getEpoch();
      String batteryPercent = String(getBattery());
    #endif

    #ifdef turnOnSD
      saveDataToSD(SD, dataToCsvRow(wagaOdczyt, nowTimestampEpoch) );
    #endif

    #ifdef GSM_turn_on
      makePostGSM( dataToJson(wagaOdczyt, nowTimestampEpoch,batteryPercent) );
    #else
      sendDataToServer( dataToJson(wagaOdczyt, nowTimestampEpoch,batteryPercent) );
    #endif

    handle_sleep();
  }

  
}

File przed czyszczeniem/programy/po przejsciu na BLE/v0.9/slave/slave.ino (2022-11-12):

/*
 * Spis pinów
 * 
 * GPIO11 - OneWire Dallas temperatura
 * 
 * GPIO7 - HX711 data
 * GPIO6 - HX711 clk
 * 
 * Karta pamięci
 * MISO D6
 * MOSI D7
 * SCK D5
 * CS D8
 * 
 */
 // https://everythingesp.com/make-your-state-variables-survive-unexpected-reboots/

//// TEMPERATURA
//#include <OneWire.h>
//#include <DallasTemperature.h>
//#define ONE_WIRE_BUS D4
//OneWire oneWire(ONE_WIRE_BUS);
//DallasTemperature sensors(&oneWire);
////--zmienne
//float tempC;
float tempC = 69;

//// WAGA
//#define pin_waga_data D1
//#define pin_waga_clk D2
//#include "HX711.h"
//HX711 scale(pin_waga_data,pin_waga_clk);
float calibration_factor = 10570; // w otoczeniu 2kg
////-- zmienne
//float pomiar_waga;
float pomiar_waga = 420;


// BLE SLAVE
#include "BLEDevice.h"
// The remote service we wish to connect to.
static BLEUUID serviceUUID("a9a5d9db-1d47-44a6-84cb-a3d00cf2a25f");
// The characteristic of the remote service we are interested in.
static BLEUUID charUUID_spanie("453a0b55-0417-4ee6-b458-83d3ff6fe054");
static BLEUUID charUUID_sensory("2aedd564-e21d-491d-a34a-6aaf984c4e3c");
static boolean doConnect = false;
static boolean connected = false;
static boolean doScan = false;
static BLERemoteCharacteristic* pRemoteCharacteristic_spanie;
static BLERemoteCharacteristic* pRemoteCharacteristic_sensory;
static BLEAdvertisedDevice* myDevice;

// INNE ZMIENNE
boolean DEBUG = true;
boolean setup_error = false;
boolean loop_error = false;
unsigned int sleep_time = 40;

// SLEEP
#define TIME_TO_SLEEP  10
#define uS_TO_S_FACTOR 1000000


// POZOSTALE FUNKCJE
static void notifyCallback(
  BLERemoteCharacteristic* pBLERemoteCharacteristic,
  uint8_t* pData,
  size_t length,
  bool isNotify) {
    Serial.println("callback detected" + String(pBLERemoteCharacteristic->toString().c_str()) );
    uint8_t minutes = pData[0];
    uint8_t seconds = pData[1];
    Serial.println("Ide spac na " + String(pData[0]) + " minut i " + String(pData[1]) + " sekund");
    Serial.flush();
    handle_sleep(minutes,seconds);
}

class MyClientCallback : public BLEClientCallbacks {
  void onConnect(BLEClient* pclient) {
  }

  void onDisconnect(BLEClient* pclient) {
    connected = false;
    Serial.println("onDisconnect");
  }
};

bool connectToServer() {
    Serial.print("Forming a connection to ");
    Serial.println(myDevice->getAddress().toString().c_str());
    
    BLEClient*  pClient  = BLEDevice::createClient();
    Serial.println(" - Created client");

    pClient->setClientCallbacks(new MyClientCallback());

    // Connect to the remove BLE Server.
    pClient->connect(myDevice);  // if you pass BLEAdvertisedDevice instead of address, it will be recognized type of peer device address (public or private)
    Serial.println(" - Connected to server");
    pClient->setMTU(517); //set client to request maximum MTU from server (default is 23 otherwise)
  
    // Obtain a reference to the service we are after in the remote BLE server.
    BLERemoteService* pRemoteService = pClient->getService(serviceUUID);
    if (pRemoteService == nullptr) {
      Serial.print("Failed to find our service UUID: ");
      Serial.println(serviceUUID.toString().c_str());
      pClient->disconnect();
      return false;
    }
    Serial.println(" - Found our service");


    // Obtain a reference to the characteristic in the service of the remote BLE server.
    pRemoteCharacteristic_spanie = pRemoteService->getCharacteristic(charUUID_spanie);
    if (pRemoteCharacteristic_spanie == nullptr) {
      Serial.print("Failed to find our characteristic UUID: ");
      Serial.println(charUUID_spanie.toString().c_str());
      pClient->disconnect();
      return false;
    }
    Serial.println(" - Found our characteristic");

    pRemoteCharacteristic_sensory = pRemoteService->getCharacteristic(charUUID_sensory);
    if (pRemoteCharacteristic_sensory == nullptr) {
      Serial.print("Failed to find our characteristic UUID: ");
      Serial.println(charUUID_sensory.toString().c_str());
      pClient->disconnect();
      return false;
    }
    Serial.println(" - Found our characteristic");

    if(pRemoteCharacteristic_spanie->canNotify())
      pRemoteCharacteristic_spanie->registerForNotify(notifyCallback);

    connected = true;
    return true;
}

class MyAdvertisedDeviceCallbacks: public BLEAdvertisedDeviceCallbacks {
 /**
   * Called for each advertising BLE server.
   */
  void onResult(BLEAdvertisedDevice advertisedDevice) {
    Serial.print("BLE Advertised Device found: ");
    Serial.println(advertisedDevice.toString().c_str());

    // We have found a device, let us now see if it contains the service we are looking for.
    if (advertisedDevice.haveServiceUUID() && advertisedDevice.isAdvertisingService(serviceUUID)) {

      BLEDevice::getScan()->stop();
      myDevice = new BLEAdvertisedDevice(advertisedDevice);
      doConnect = true;
      doScan = true;

    } // Found our server
  } // onResult
}; // MyAdvertisedDeviceCallbacks

void handle_sleep(uint8_t minutes, uint8_t seconds) {
  Serial.println("czas spania: " + String(minutes) + " minut i " + String(seconds) + " sekund" );
  Serial.flush();
  esp_sleep_enable_timer_wakeup(TIME_TO_SLEEP * uS_TO_S_FACTOR);
  //esp_sleep_enable_timer_wakeup( (minutes*60+seconds) * uS_TO_S_FACTOR);
  esp_deep_sleep_start();
}

void setup() {
  Serial.begin(115200);
  Serial.println("Starting Arduino BLE Client application...");
  BLEDevice::init("ESP32 SLAVE");

  // Retrieve a Scanner and set the callback we want to use to be informed when we
  // have detected a new device.  Specify that we want active scanning and start the
  // scan to run for 5 seconds.
  BLEScan* pBLEScan = BLEDevice::getScan();
  pBLEScan->setAdvertisedDeviceCallbacks(new MyAdvertisedDeviceCallbacks());
  pBLEScan->setInterval(1349);
  pBLEScan->setWindow(449);
  pBLEScan->setActiveScan(true);
  pBLEScan->start(5, false);
}

long timer = 0;

void loop() {
  if (doConnect) {
    if (connectToServer()) {
      Serial.println("We are now connected to the BLE Server.");
    } else {
      Serial.println("We have failed to connect to the server; there is nothin more we will do.");
    }
    doConnect = false;
  }
  
    
  if (connected)  {
    if(timer + 10000 < millis() ) {
      timer = millis();
      String newValue = String(pomiar_waga)+","+String(tempC)+"," + String(millis()/1000);
      Serial.println("Setting new characteristic value to \"" + newValue + "\"");
      
      // Set the characteristic's value to be the array of bytes that is actually a string.
      pRemoteCharacteristic_sensory->writeValue(newValue.c_str(), newValue.length());
    }
    
  }else if(doScan){
    BLEDevice::getScan()->start(0);  // this is just example to start scan after disconnect, most likely there is better way to do it in arduino
  }
}

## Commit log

2022-03-02 testy na nodemcu oraz początek próby obługi zewnętrznego esp8266
    w celu takim, że można te kompononty wysłać do domu i zrobić szybki prototyp do wyświetlania informacji z wagi,temperatury itp przed rozpoczęciem sezonu zbiorów, dzięki temu można zacząć zbierać (skr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
    [linki do poradnikow.ods]
2022-03-07 szamotanie się z AT, destabilizacja firmware, odkrycie stulecia że można użyć arduino IDE bezpośrednio na esp-01
2022-03-13 spis elementów
    [spis_elementow_przeznaczonych_na_projekt.ods]
2022-03-16 czujnik wibracji done
    [spis_elementow_przeznaczonych_na_projekt.ods]
2022-03-23 telnet server dzialajacy
    [linki do poradnikow.ods, spis_elementow_przeznaczonych_na_projekt.ods]
2022-04-06 projekt v1 - offline pomiary - poczatek (Sensor.Temperatura)
    [spis_elementow_przeznaczonych_na_projekt.ods]
2022-04-07 Timer&Sleep synchornizowane
    kompiluje sie, dzialanie niesprawdzane
2022-04-10 działający offline pomiar ze spaniem bez interruptu
2022-04-26 job done v3 zbieranie offline
    TODO ostatecznie rozwiązać kwestię akumulatora, bo te które mam są risky dla 3v3 (dają do 3.8, a wg dokumentacji 3.6 [wg hakierów nawet 4 szło ale się grzeje no i ryzykowne]), ale też są za słabe dla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
    [dopasowanie pinow na plytce.ods]
2022-05-07 online proba1 v1
    [dopasowanie pinow na plytce.ods]
2022-06-15 esp32 read from site
    esp32 correctly connects through wifi to my site at pp and gets whole information (example_wificlient.ino)
    [15czerwiec_show_response_from_php.ino, master_v2.ino]
2022-06-22 start konwersji esp-master na esp32 + pierwsze kroki komunikacji calościowej
2022-06-26 "definitywna" jsonowa struktura i dziala wysylanie i intepretowanie
    [dopasowanie pinow na plytce.ods]
2022-06-26 php insert unique
    query przetestowane, dzialanie php nie, unique poniewaz te same krotki moga trafic do DB z roznych zrodel (esp-master ->gsm->DB) ale też (esp-master->android -> gsm->DB) itp
2022-06-26 /index( show) & /insert (insert)
2022-10-22 szkic do lutowania , work in progress
    [wymiary modułow.xlsx]
2022-11-04 poczatki insert into db
2022-11-05 teoretycznie dostosowane insertowanie do bazy
2023-01-24 układy elektryczne i prezentacja
    [esp-master-nodeMCU.kicad_pcb, esp-master-nodeMCU.kicad_sch, esp-slave-nodeMCU.kicad_pcb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]
2023-03-09 kalibracja wagi krzywą 0-15kg
2023-04-19 esp merged kicad
    [esp-merged_v1.kicad_pcb, esp-merged_v1.kicad_sch]
2023-04-26 postępy projektowania PCB
    [esp-merged_v1.kicad_sch]
2023-04-28 postepy kicad, footprinty
    [esp-merged_v1.kicad_sch]
2023-04-28 kicad footprint sim800l
    [esp-merged_v1.kicad_sch]
2023-05-01 pcb skonczone?
    [esp-merged_v1.kicad_pcb, esp-merged_v1.kicad_sch]
2023-05-01 esp merged pcb v2 (dostosowane pod obudowe)
    [esp-merged_v2.kicad_pcb, esp-merged_v2.kicad_sch]
2023-07-30 gsm working in merged.ino, interface for BLE-read-battery
2023-09-21 reorder most of files, yoink "Aplikacja 6 sem" to "kod aplikacja"
    [dopasowanie pinow na plytce.ods, esp-master-nodeMCU.kicad_pcb, esp-master-nodeMCU.kicad_sch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]
2023-11-08 2 wersja, fix na pierwsza
    [esp-merged_v2-B_Cu.gbr, esp-merged_v2-B_Mask.gbr, esp-merged_v2-B_Paste.gbr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]
2023-11-08 wake up btn and led in code
2023-11-09 wake up by btn and led
2023-11-12 początki fixów do schematu pcb v2
    [esp-merged_v2.kicad_sch]
2023-11-12 add battery level to chart and saving in table
2024-02-17 a
    a
    [pomiary.csv]
2024-02-25 time synch (not tested)
    cant connect to BLE, works once per 10 tries (after resetting)
    [mergred_slave_master_v3.ino]
2024-02-28 maly progress pcb
    [esp-merged_v2.kicad_sch]
2024-04-03 app front adjustments
    [esp-merged_v2.kicad_sch]
2024-05-05 ledy zmiana
2024-05-13 timer dzialajacy wraz z async initem
    przeanalizować ostatni .txt, poprawic postGSM tak jak poprawiono initGSM
